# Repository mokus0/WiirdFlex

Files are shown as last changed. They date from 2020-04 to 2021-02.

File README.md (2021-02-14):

See also the [project work log](https://bitbuilt.net/forums/index.php?threads/wiirdflex.3365/)

Features
---------

The final board designs here will include two flexible PCBs designed to be mounted on top (CPU/GPU side) and bottom (AVE side) of the Wii.  These will provide the following features:

* Power supplies (top)
* Temperature sensor (top)
* External communication ports
  * USB ports (2x, top)
  * SD card (top)
  * Gamecube controllers (4x, bottom)
  * Gamecube memory cards (2x, bottom)
  * Extra GPIO (6x, bottom)
* Wii component relocations
  * Bluetooth module (top, external)
  * WiFi module (bottom, external)
  * NAND (bottom, on flex)
  * MX (bottom, external)
  * U10 (bottom, on flex)
  * AVE (bottom, external), including:
    * I2C, I2S, digital video and "mode" pin
    * optional pull resistors on flex for mode control
* Other (pins available for these things)
  * U-AMP/wiiHUD compatibility
  * RVL-DD compatibility
* *MAYBE* loop-around option, fold over and connect extra-signals tail of top flex to bottom flex to bring top side signals out on bottom side

Connection Strategies
----------------------

Top Side:
  TODO: the following is a general idea of the order of operations, but parts of some tasks may interleave with others.  There may also be other, better, orders to follow (I'm thinking of an alternate strategy using low-temp solder paste).  Reorganize into an actual instruction list.
  
  TODO: any extra alignment aid? 3d printable pin jig for mounting holes maybe?
  TODO: make sure instruction list is optimized for incremental testing

  0. Prep:
    a. TODO: other prep work (install bottom flex, perform U10/NAND/MX/AVE relocations, etc. and test) 
    b. Trim Wii
    c. Desolder bulk caps (TODO: references), label and set aside, or ensure you have replacements ready (TODO: suggest replacement options)
    d. Desolder other components:
      i.    C1, C2, C6, U5: remove and discard, these are not needed
      ii.   RA10, RA11, R163: remove. If using SD relocation feature, retain these or obtain clean replacements (TODO: characterize needed replacements)
      iii.  R71: remove.  If using Aurelio's NAND relocation flex, this relocates to R1 on that board.  If using WiirdFlex Bottom, [TODO: describe where it goes].  Otherwise, you're in Advanced User territory and you should know what to do with it.
      iv.   R19: remove.  [TODO: what's this for, does it need to be re-added somewhere?]
      v.    RA13: remove.  If using WiirdFlex bottom, this will be relocated to [TODO: describe location].  TODO: describe how to properly relocate this if not using WiirdFlex Bottom.
    e. If using bluetooth and rev 0 flex, cut out bluetooth trace access window on flex
  
  1. Power
    a. solder bulk caps to flex, ensuring good coat (thin but even) of solder on bottom side (before doing USB)
    b. prepare thermal sensing solution by following step 4a
    c. prepare USB by following steps 2[a-b]
    d. prepare BT by following steps 3[a-e]
    e. prepare SD by fololwing steps 5[a-b]
    f. align flex and solder bulk caps
    g. complete remaining steps of sections 2-5

  2. USB
    a. solder magnet wire into each via, leaving a bit of length
    b. thread magnet wires through corresponding holes on flex
    c. align flex and solder down
    d. trim wires flush

  3. Bluetooth:
    a. cut data traces
    b. shave data traces
    c. solder magnet wire to data traces and sense via
    d. thread through flex
    e. place and align flex
    f. solder wires to flex
    g. trim wires

  4. Thermal sensing
    a. solder components to flex
    b. peel adhesive, align whole flex and adhere to Wii
  
  5. SD
    a. solder magnet wire into SD_CLK via
    b. thread wire through flex
    c. align flex and solder down
    d. trim wire flush
    e. solder termination resistors (TODO: references)

Bottom side:
  TODO: this section is a work in progress. it currently is just a general outline of the planned connections from a couple different perspectives.  pin counts are estimates.
  
  - Components to remove:
    - WiFi termination resistors (TODO: relocate onto flex) (TODO: decide whether to include cutout on flex for those that don't want to remove them)
    - all AV-related components (TODO: including i2c pull-ups? one or both?)
  
  - A/V [relocation]: 19 pins
    - I2S audio (4 pins)
      - MCLK, WS, SD, SCK
    - digital video
      - V[0:7], "54"
    - I2C (wiiHUD/RVL-DD)
      - SDA, SCL
    - SPI ([RVL-DD](https://bitbuilt.net/forums/index.php?threads/rvl-dd-documentation.3951/))
      - CS, CK, DI
    - M(mode)
    - TODO: check for others needed by AVE but not listed here
  - MX [relocation]: 9 pins
  - NAND [relocation]: (17 pins, but not offboard)
  - Fan control: 1 pin
  - GC memory cards: 12 pins
  - GC controllers: 4 pins
  - Reset: 1 pin (shared with MX? not sure)
  - Extra test points: 6 pins
  - WiFi: 6 pins

  External connections:
    - main ZIF connection for portables [27 signal + ?? power/GND]
      - Power (3.3v, 1.8v, GND) [??]
        - this is to provide power from Wii to support circuitry to avoid need for extra routing from the power management system, NOT to power the Wii itself
      - Digital video [9]
      - I2S [4]
      - AVE I2C [2]
      - TP223 (Headphone detect in [wiiHUD connection diagram](https://bitbuilt.net/forums/index.php?threads/gboy-rev3.2959/#lg=thread-2959&slide=1)) [1]
      - SPI CS for RVL-DD [1]
      - MX [9], including 2 pins also used for RVL-DD SPI
      - P1 Controller [1]
    - DLC ZIF connection (some of these probably are dupes of others used elsewhere) [29 signal + ?? power/GND]
      - Fan control [1]
      - Reset [1]
      - GC mem cards [12]
      - Extra test points [5]
      - WiFi [6]
      - Video mode [1]
      - P2-4 controllers [3]
    - additional components:
      - pull resistors for "mode" pin
      - voltage detector (U10) with decoupling cap(s)
      - source termination resistor arrays as needed (digital video, i2s, etc)
      - other pull resistors as needed (reset, I2C, GC controllers, mem cards, etc)
      - any other components removed from Wii
    - ZIF pin ordering preferences? a few ideas, probably contradicting each other a bit:
      - probably match wii ordering for AVE pins
      - i2c near bottom-right (in Altium layout orientation) for ease of transition across to PMS board
      - i2s also near same, since audio codec will be in back case

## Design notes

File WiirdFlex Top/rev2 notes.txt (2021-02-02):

Top flex improvements

stackup
  - update with true stackup from fab (0.2mm total thickness, 0.1mm stiffener)
  - consider more adhesive
  - readjust USB traces for impedance after stackup change

other
  - fix missing cutout
  - consider additional cutouts to avoid need to remove some components:
    - U5 cluster
    - R19
    - RA13
  - extra ceramic cap for 1.8V rail

silkscreen
  - logo/board name
  - version info, date, project URL, etc
  - polarity marks for caps
  - cut lines for extra-signals tail?
  - component labels

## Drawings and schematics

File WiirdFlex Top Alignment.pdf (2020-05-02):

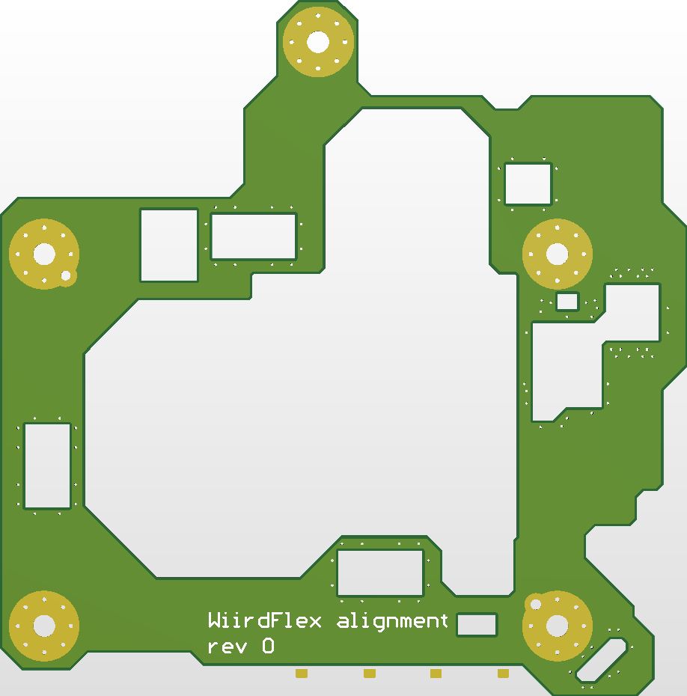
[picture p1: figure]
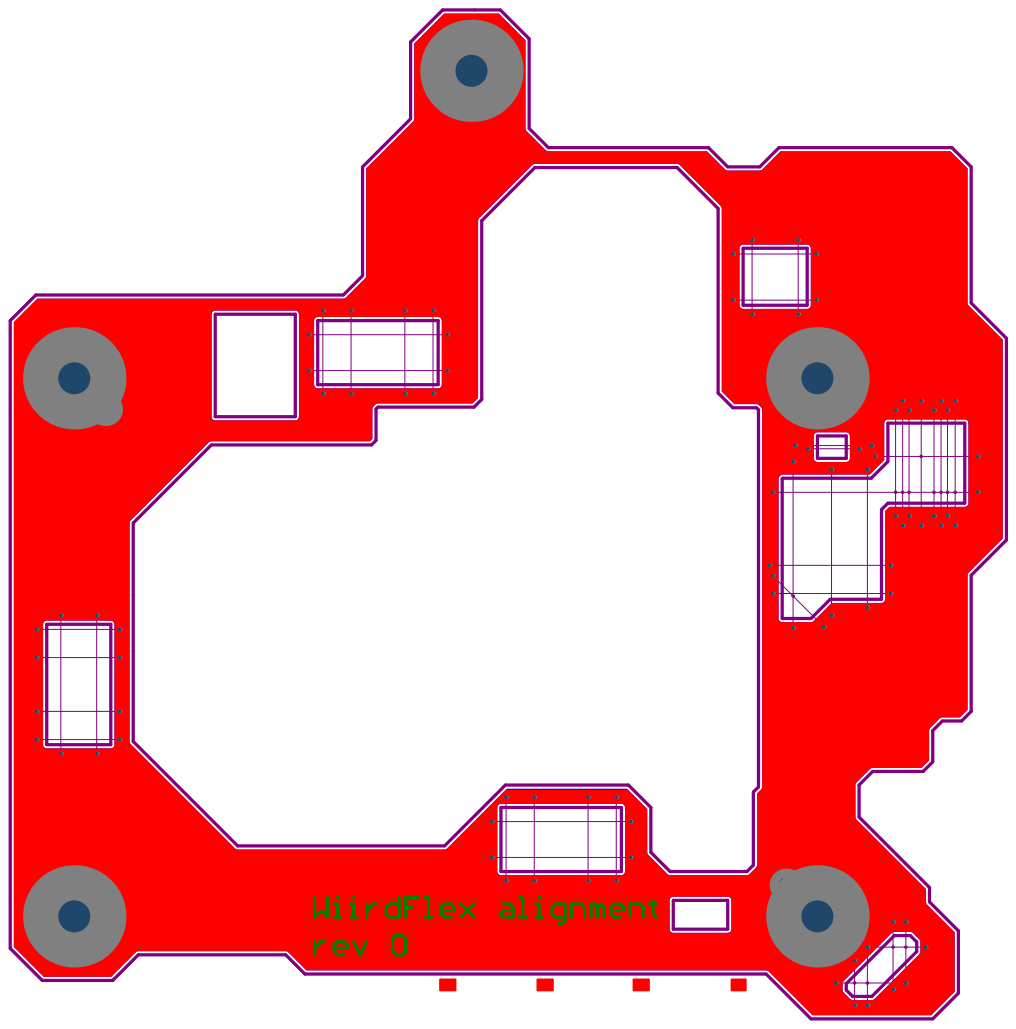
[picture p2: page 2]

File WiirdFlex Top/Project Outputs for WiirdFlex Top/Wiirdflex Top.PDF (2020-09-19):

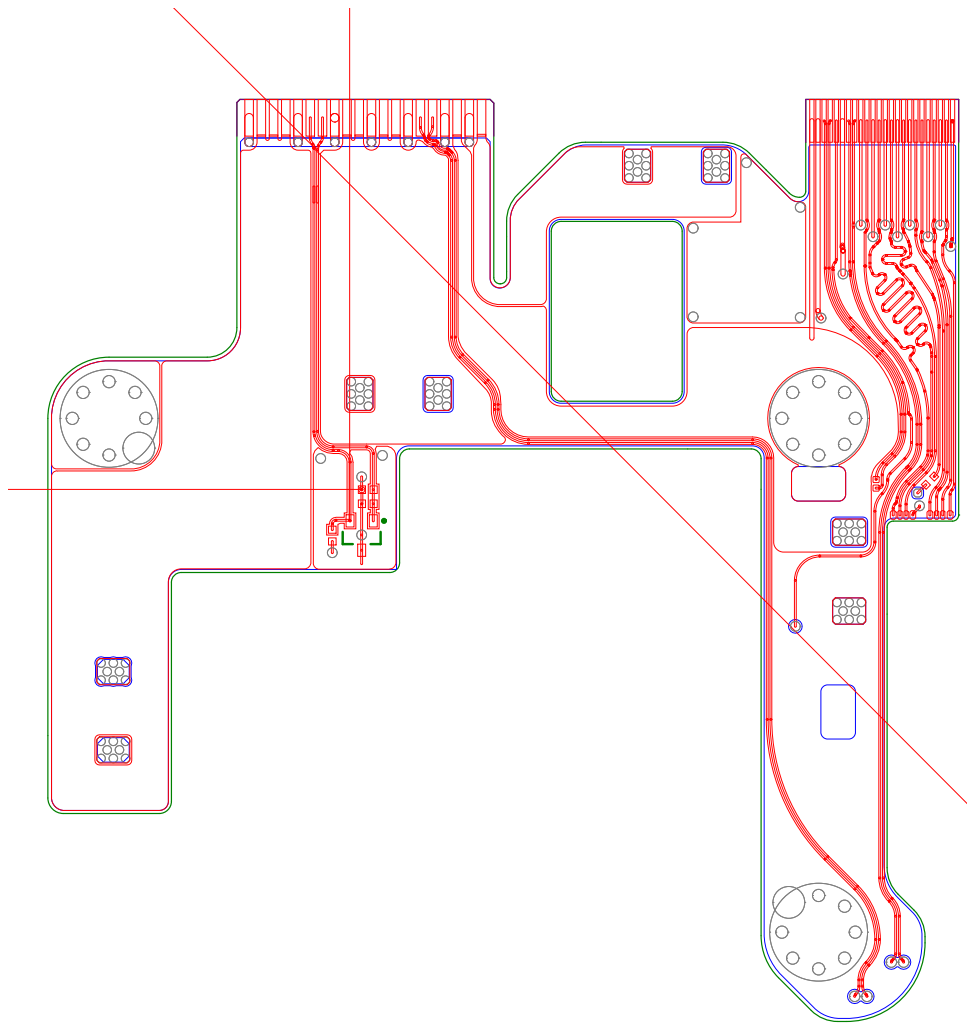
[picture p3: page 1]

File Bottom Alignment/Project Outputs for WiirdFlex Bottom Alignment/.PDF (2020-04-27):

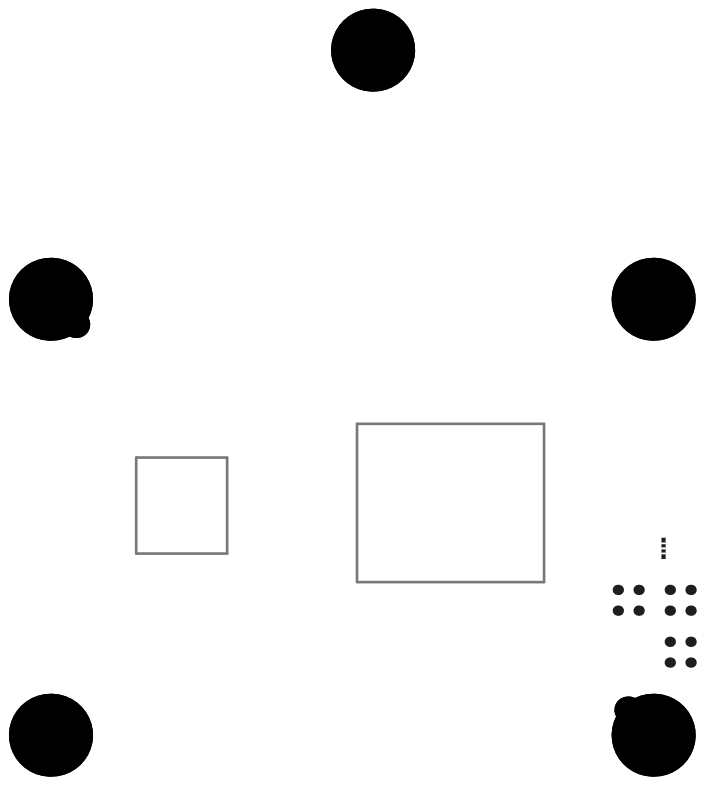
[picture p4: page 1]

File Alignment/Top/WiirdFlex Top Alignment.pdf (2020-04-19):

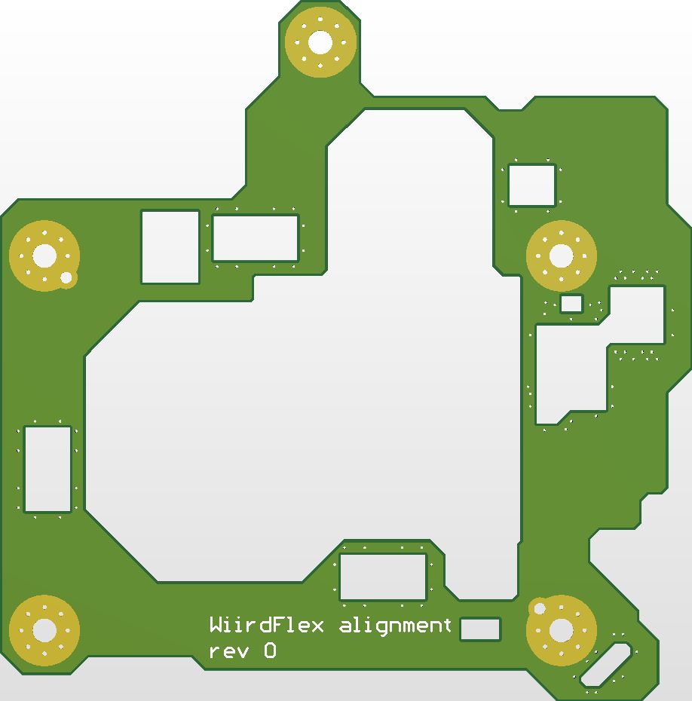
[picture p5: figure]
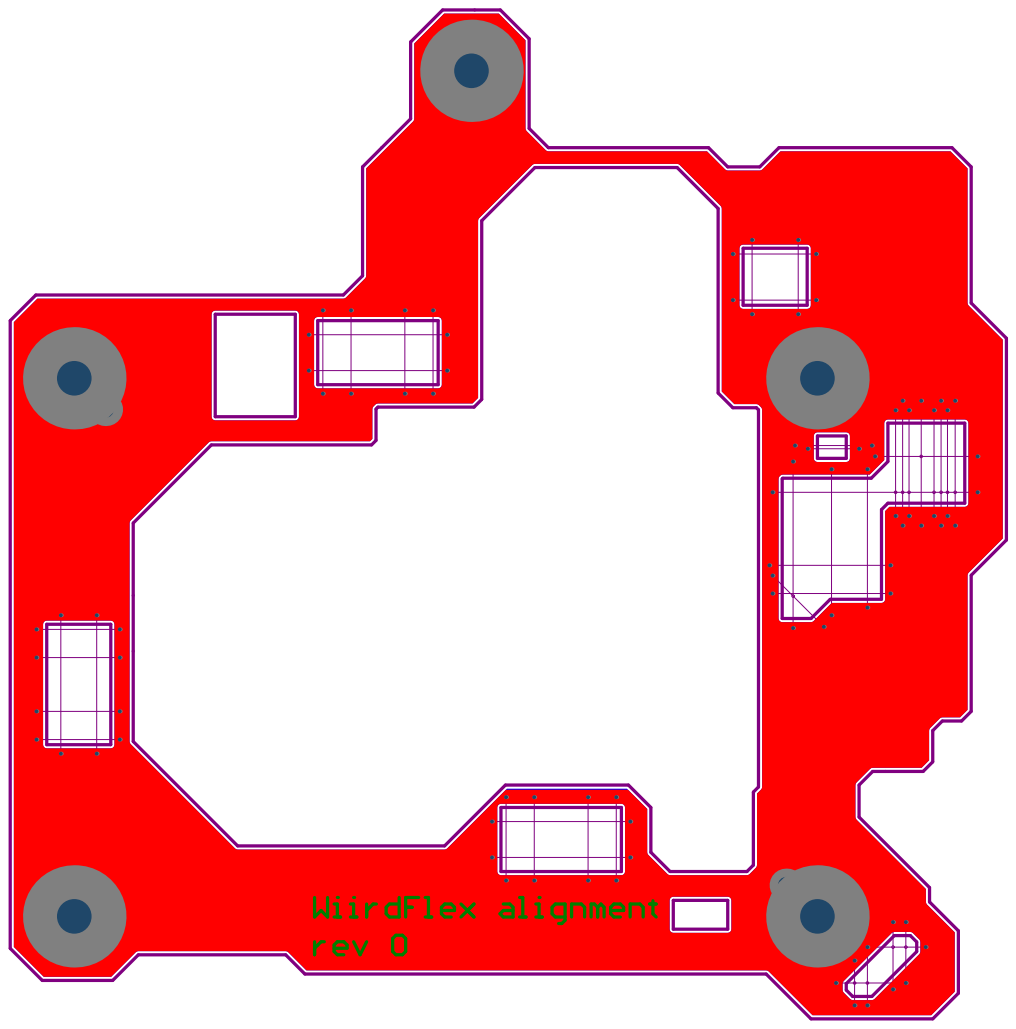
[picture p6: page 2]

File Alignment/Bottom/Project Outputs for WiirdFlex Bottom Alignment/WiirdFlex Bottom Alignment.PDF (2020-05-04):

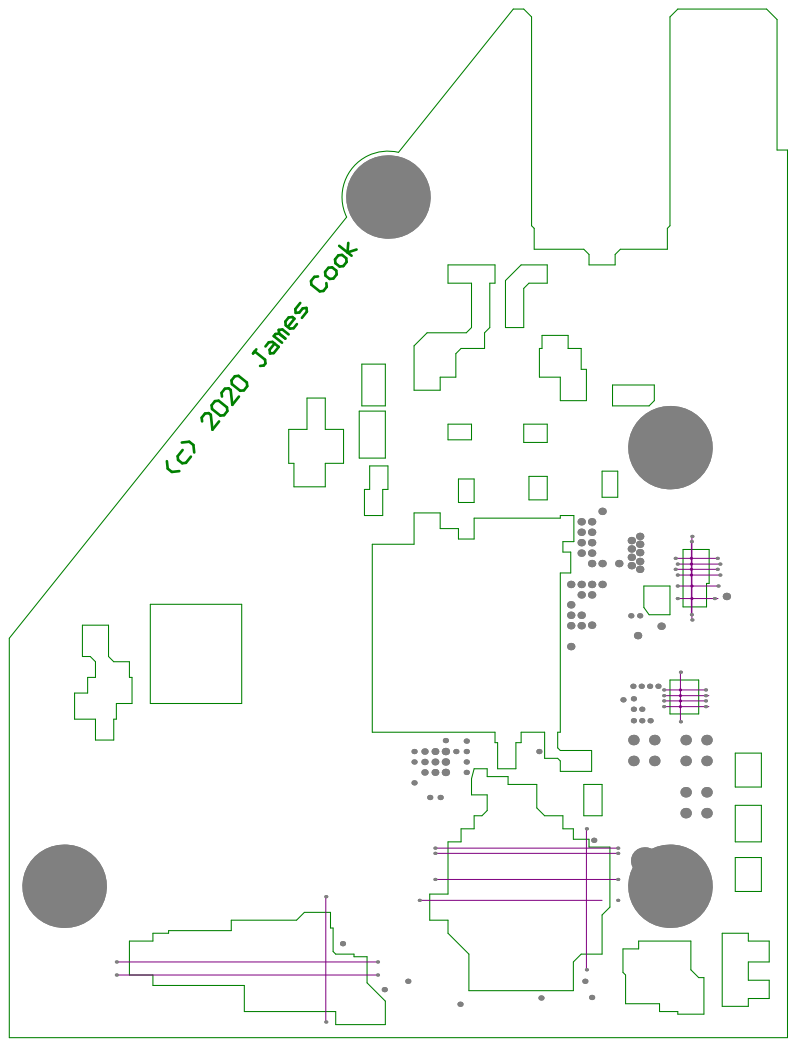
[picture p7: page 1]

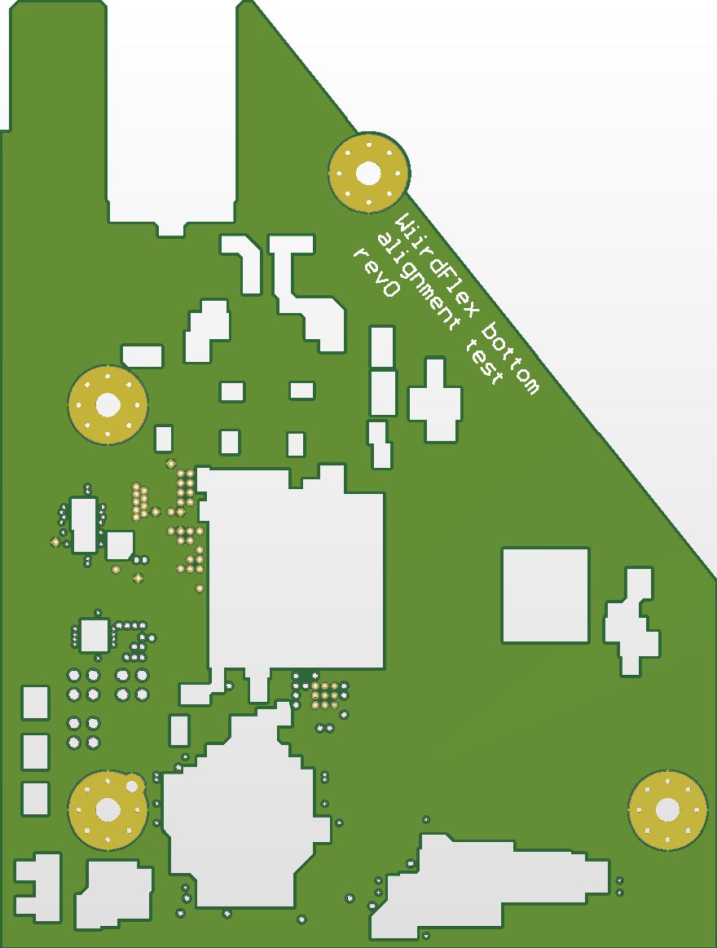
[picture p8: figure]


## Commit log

2020-04-19 initial placement and board outline for top side
    [WiirdFlex Top.PcbDoc, WiirdFlex Top.SchDoc, WiirdFlex.PcbLib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]
2020-04-19 adding an alignment check fixture for top
    [WiirdFlex Top Alignment.PcbDoc, WiirdFlex Top Alignment.SchDoc, WiirdFlex.PcbLib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]
2020-04-19 preparing some gerbers
    [WiirdFlex Top Alignment.PcbDoc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]
2020-04-19 as ordered (top fit check)
    [WiirdFlex Top Alignment.PcbDoc, WiirdFlex.PcbLib, WiirdFlex.PrjPcb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]
2020-04-19 organizing stuff a bit
    [WiirdFlex Top Alignment.PrjPcb]
2020-04-19 moving top alignment into subdir
    [WiirdFlex Top Alignment.PcbDoc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]
2020-04-27 yeah, this is the commit message i'm gonna go with
    sorry, my capacity to care is spent today.
    [WiirdFlex Bottom Alignment.PcbDoc, WiirdFlex Bottom Alignment.PrjPcb, WiirdFlex Bottom Alignment.SchDoc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]
2020-05-02 updated some geometries based on first test pcb...
    ... and added a bunch more footprints showing
    locations of target vias, pads, etc.
    This should now cover pretty much all of the things,
    except for the disk drive which I have no intention
    of covering. Unless maybe it's a standard-ish interface
    and can interface to non-Wii disk drives, since that
    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
    [WiirdFlex Bottom Alignment.PcbDoc, WiirdFlex Bottom Alignment.PrjPcb, WiirdFlex Bottom Alignment.SchDoc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]
2020-05-03 refactor keepouts a bit, add lots of alignment test stuff, start to define board shape
    [WiirdFlex Bottom Alignment.PcbDoc, WiirdFlex Bottom Alignment.PrjPcb, WiirdFlex Bottom Alignment.SchDoc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]
2020-05-03 sketching out what I think the next alignment pcb will look like
    gonna sleep on it, review tomorrow, and hopefully order.
    [WiirdFlex Bottom Alignment.PcbDoc, WiirdFlex Bottom Alignment.SchDoc, WiirdFlex.PcbLib]
2020-05-03 getting ready to order bottom test fit board
    * added some ground connection points
    * adjusting board outline a bit to support some plated vias
    of various sizes (which I will use to experiment a bit with
    some ideas for soldering to the Wii)
    * one last pass through, adjusting alignment with compendium
    images
    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
    [WiirdFlex Bottom Alignment.PcbDoc, WiirdFlex Bottom Alignment.PrjPcb, WiirdFlex Bottom Alignment.SchDoc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]
2020-05-04 generate gerber files and order
    [WiirdFlex Bottom Alignment.PrjPcb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]
2020-05-11 add a quick test thingy for testing some FPC stuff
    two potential connectors. I want to test fit with an FPC tab connector
    and also test for current handling.
    [FPC connectors.PcbLib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]
2020-05-16 starting work on actual flex pcb for top side
    [TempSense.SchDoc, WiirdFlex Top.PcbDoc, WiirdFlex Top.PrjPcb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]
2020-05-17 adding some measurements for power connection
    [WiirdFlex Top.PcbDoc, WiirdFlex Top.PrjPcb, WiirdFlex Top.SchDoc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]
2020-05-17 more geometry, stackup, pin assignments, etc
    [WiirdFlex Top.PcbDoc, WiirdFlex Top.PrjPcb, WiirdFlex Top.SchDoc]
2020-05-17 a bit more adjustment of power connection length
    [WiirdFlex Top.PcbDoc]
2020-05-18 more progress, starting to route power
    [WiirdFlex Top.PcbDoc, WiirdFlex Top.PrjPcb, WiirdFlex Top.SchDoc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]
2020-07-12 connected all power rails
    [TempSense.SchDoc, WiirdFlex Top.PcbDoc, WiirdFlex Top.PrjPcb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]
2020-07-26 adjusted length of tail based on prototype test fit
    [WiirdFlex Top.PcbDoc, WiirdFlex Top.PrjPcb]
2020-07-26 starting to plan and route extra connector
    [WiirdFlex Top.PcbDoc, WiirdFlex Top.SchDoc, WiirdFlex.PcbLib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]
2020-07-26 reduced board size and partially routed signals for extra tab
    [TempSense.SchDoc, WiirdFlex Top.PcbDoc, WiirdFlex Top.SchDoc]
2020-09-19 almost ready for ordering!
    [WiirdFlex Top.PcbDoc, WiirdFlex Top.SchDoc, WiirdFlex.PcbLib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]
2021-01-03 added a few minor notes to silkscreen and generated gerber outputs
    [WiirdFlex Top.GBL, WiirdFlex Top.GBO, WiirdFlex Top.GBP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]
2021-01-24 moving some stuff around
    [WiirdFlex Bottom Alignment.PcbDoc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]
2021-01-25 starting to sketch out bottom flex schematic
    [AV.SchDoc, GameCube.SchDoc, MX.SchDoc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]
2021-02-02 i dunno, stuff i guess.
    this isn't my job, i don't have to have good commit messages.
    [NAND.SchDoc, WiirdFlex Bottom.PcbDoc, WiirdFlex Bottom.PrjPcb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]
2021-02-14 add NAND footprint, start adding keepouts, add GND pin for GC controller
    [GameCube.SchDoc, NAND.SchDoc, WiirdFlex Bottom.PcbDoc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]
2021-02-14 starting to set up interface vias on bottom side
    [WiirdFlex Bottom.PcbDoc, WiirdFlex.PcbLib]
2021-02-14 add keep-out areas for components that won't be removed and README comments for those that will
    [WiirdFlex Bottom.PcbDoc, WiirdFlex Bottom.SchDoc, WiirdFlex.PcbLib]
